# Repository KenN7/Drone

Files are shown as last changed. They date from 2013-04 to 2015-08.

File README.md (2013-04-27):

   ___          _                                     __ _   _               
  / __\___   __| | ___ _ __   __ _ _ __ ___   ___    /__\ |_| |__   ___ _ __ 
 / /  / _ \ / _` |/ _ \ '_ \ / _` | '_ ` _ \ / _ \  /_\ | __| '_ \ / _ \ '__|
/ /__| (_) | (_| |  __/ | | | (_| | | | | | |  __/ //__ | |_| | | |  __/ |   
\____/\___/ \__,_|\___|_| |_|\__,_|_| |_| |_|\___| \__/  \__|_| |_|\___|_|   
-----------------------------------------------------------------------------

Sources i use to build my quadrotor drone, you will find the source code and
the electronics based on dsPIC33 architecture.

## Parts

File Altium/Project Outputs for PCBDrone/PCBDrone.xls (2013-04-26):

Comment | Description | Designator | Footprint | LibRef | Quantity | Value
CAP | Capacitor | C7, C9, Cde, Cdecoup1, Cdecoup2, Cdecoup4 | C0805C | CAP | 6.0 | 10uF, 100nF, 100pF
CAP Pol | Polarized Capacitor | Creg1, Creg2 | RB.1/.3 | CAP Pol | 2.0 | 100uF, 220uF
LED2 | Typical RED, GREEN, YELLOW, AMBER GaAs LED | D1 | LED1206G | LED2 | 1.0
LED | Typical LED | Ddebug1 | LED1206R | LED | 1.0
LED | Typical LED | Ddebug2 | LED1206Y | LED | 1.0
LED | Typical LED | Ddebug3 | LED1206G | LED | 1.0
Diode 1N4001 | 1 Amp General Purpose Rectifier | DR1, DR2 | DO-41 | Diode 1N4001 | 2.0
200mA | Standard Fuse Holder | Fuse | Fuse Holder 5x20mm | Fuse | 1.0
Hole | Mounting Hole for screws | HOLE1, HOLE2 | SCREW | Hole | 2.0
Switch logique | Slide Switch with 2 positions | INT1 | Switch sur cosses 5.08mm | SW-SPDT | 1.0
Batterie | Header, 2-Pin | P1 | TERM2W-3.5 | Header 2 | 1.0
Header femelle | Header, 6-Pin | Paccelgyro | HDR1X6 | Header 6 | 1.0
alarme batterie faible | Header, 2-Pin | Palarm | HDR1X2 | Header 2 | 1.0
Header femelle | Header, 7-Pin | Pan | HDR1X7 | Header 7 | 1.0
jumper bind | Header, 2-Pin | Pbind | HDR1X2J | Header 2 | 1.0
Header 2 | Header, 2-Pin | Pext, Pext2 | TERM2W-3.5 | Header 2 | 2.0
PICkit | Header, 6-Pin, Right Angle | Pickit | HDR1X6H | Header ICSP | 1.0
Header bat | Header, 3-Pin | Prec1 | HDR1X3 | Header 3 | 1.0
Header thro | Header, 3-Pin | Prec2 | HDR1X3 | Header 3 | 1.0
Header aile | Header, 3-Pin | Prec3 | HDR1X3 | Header 3 | 1.0
Header elev | Header, 3-Pin | Prec4 | HDR1X3 | Header 3 | 1.0
Header rudd | Header, 3-Pin | Prec5 | HDR1X3 | Header 3 | 1.0
Header gear | Header, 3-Pin | Prec6 | HDR1X3 | Header 3 | 1.0
Header aux1 | Header, 3-Pin | Prec7 | HDR1X3 | Header 3 | 1.0
Header 3 | Header, 3-Pin | Psend1, Psend2, Psend3, Psend4, Pservo | HDR1X3 | Header 3 | 5.0
Header 2 | Header, 2-Pin | Puart | HDR1X2 | Header 2 | 1.0
RES | Resistor | R1, Rd1, Rd2, Rd3, Rp1, Rpup | C0805R | RES | 6.0 | 10k, 60
PTB78560x | Texas Instruments Regulators | Reg | PTB78560x | PTB78560x | 1.0
LM2937IMP-3.3 | 500 mA Low Dropout Regulator | Reg3 | TO-220-AB | LM2937IMP-3.3 | 1.0
SPST-NO | Tactile Switch 7.3mm, SMD | reset | SPST-NO | SPST-NO | 1.0
RES | Resistor | Rset2 | AXIAL-0.3 | RES | 1.0 | 14.3k
dsPIC33FJ64MC804-I/PT | High-Performance 16-bit Digital Signal Controller, 64 KB Flash, 16 KB RAM, 44-Pin TQFP, Industrial Temperature | U1 | TQFP-PT44_N | dsPIC33FJ64MC804-I/PT | 1.0

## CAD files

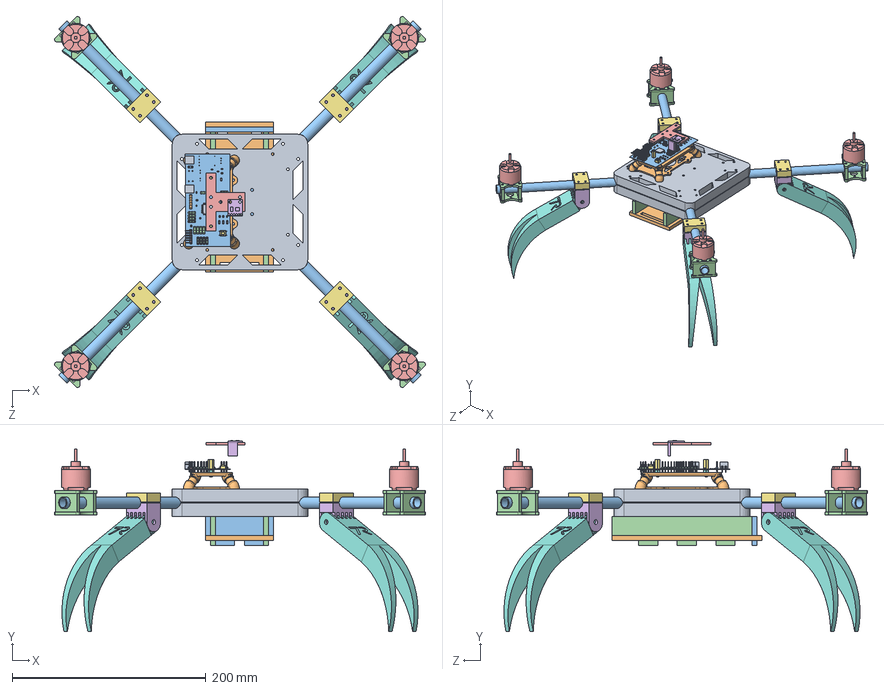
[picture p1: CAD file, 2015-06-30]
SolidWorks/Quadcopter V2.SLDASM
383.3 x 197.8 x 383.3 mm
Base V2
Anneau de fixation x 4
Tube carbone x 4
Support moteur x 4
moteur x 4
Fixation pied (bot) x 4
Fixation pied (top) x 4
Pied x 4
Base V2 (top)
Anti-vibration complet
Board
C0805C x 6
SW3dPS-LED1206G_Extruded x 2
SW3dPS-LED1206G_Extruded4 x 2
SW3dPS-LED1206G_Extruded2 x 4
SW3dPS-LED1206G_Extruded1 x 2
SW3dPS-LED1206G_Extruded3 x 2
SW3dPS-LED1206G_Board x 2
SW3dPS-LED1206R_Board
SW3dPS-LED1206R_Extruded3
SW3dPS-LED1206R_Extruded1
SW3dPS-LED1206R_Extruded x 2
SW3dPS-LED1206R_Extruded4
SW3dPS-LED1206R_Extruded2
SW3dPS-LED1206Y_Board
SW3dPS-LED1206Y_Extruded2 x 2
SW3dPS-LED1206Y_Extruded4
SW3dPS-LED1206Y_Extruded3
SW3dPS-LED1206Y_Extruded
SW3dPS-LED1206Y_Extruded1
User_Library-Spacer-M3-10mm x 2
User_Library-Female_screw_M3 x 2
User_Library-CTB93HD_2 x 2
pin_header_aw140-eg-g06d
pin_header_aw140-eg-g02d
pin_header_aw140-eg-g03d x 21
pin_header_aw140-ea-g06h
SW3dPS-0805_SMD_Resistor x 7
CircuitWorks-TACT_SMD_6X6
User_Library-TQFP-44_pins_TQFP_pin_TQFP_035_1 x 44
User_Library-TQFP-44_body_10x1_TQFP_10x10_1
Boite batterie (bot)
Boite batterie (fond)
Boite batterie (side) x 2
Support accelero
Accelero

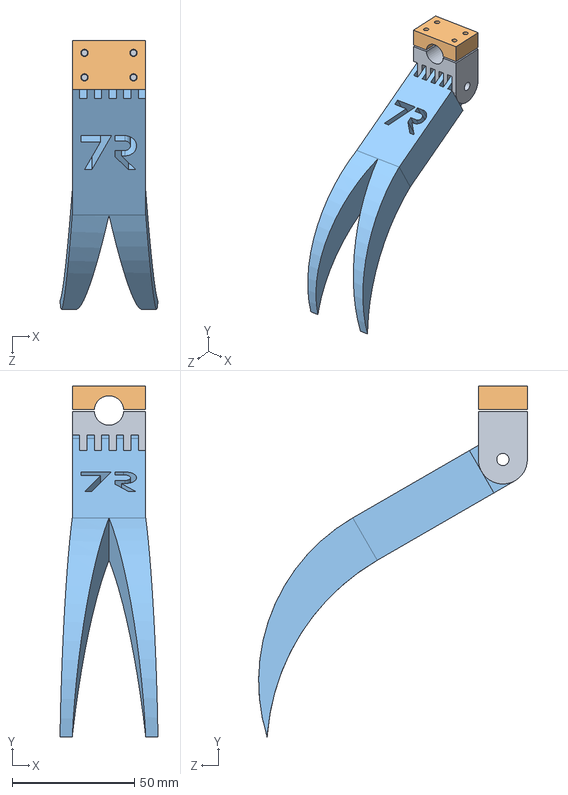
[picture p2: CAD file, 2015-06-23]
SolidWorks/Pied complet.SLDASM
40.0 x 143.3 x 109.7 mm
Fixation pied (bot)
Fixation pied (top)
Pied

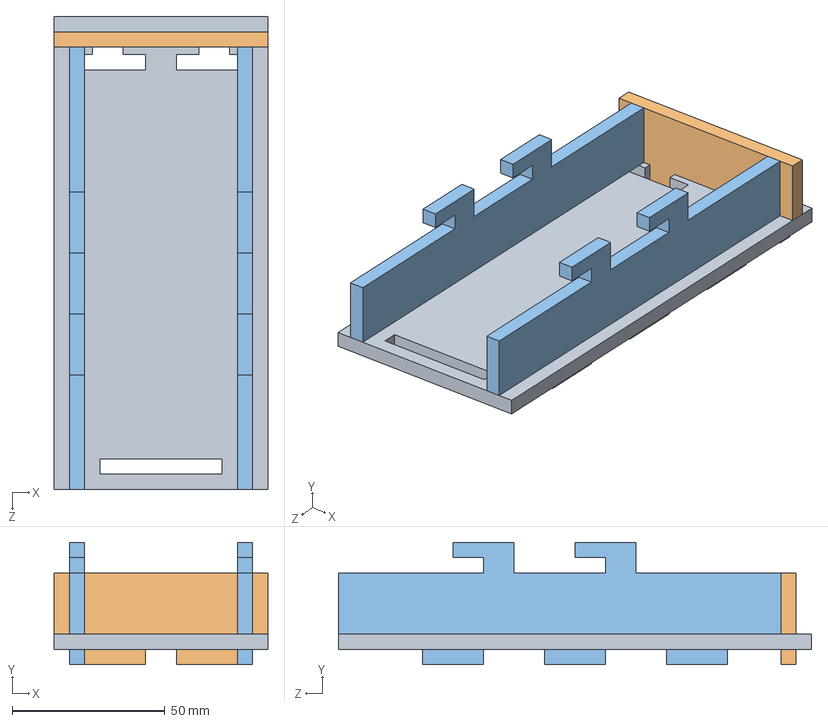
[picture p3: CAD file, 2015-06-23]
SolidWorks/Boite batterie.SLDASM
70.0 x 40.0 x 155.0 mm
Boite batterie (bot)
Boite batterie (fond)
Boite batterie (side) x 2

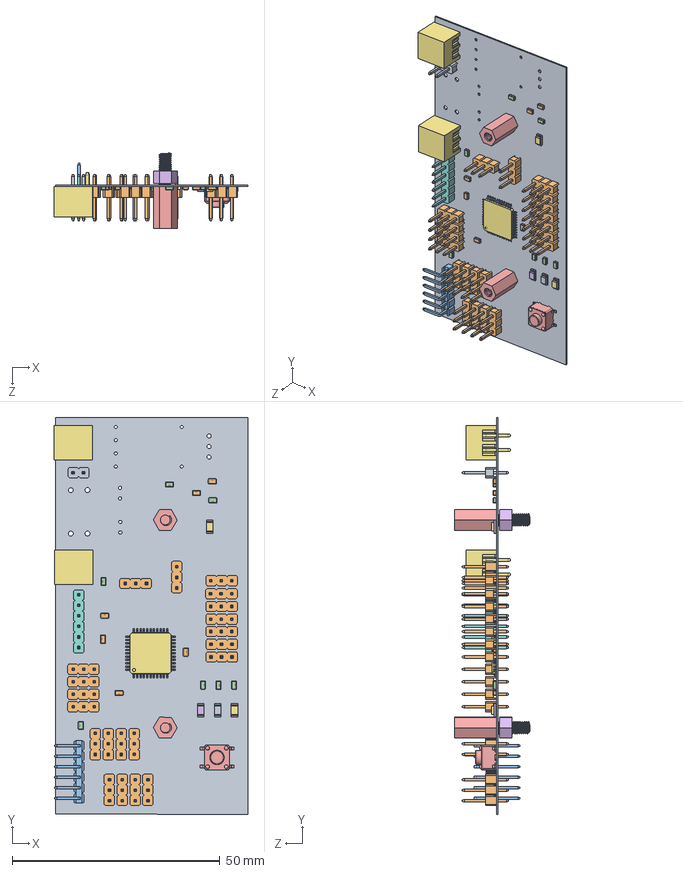
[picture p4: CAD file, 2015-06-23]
SolidWorks/PCBdroneV21.sldasm
46.7 x 95.6 x 18.2 mm
Board
C0805C x 6
SW3dPS-LED1206G_Extruded x 2
SW3dPS-LED1206G_Extruded4 x 2
SW3dPS-LED1206G_Extruded2 x 4
SW3dPS-LED1206G_Extruded1 x 2
SW3dPS-LED1206G_Extruded3 x 2
SW3dPS-LED1206G_Board x 2
SW3dPS-LED1206R_Board
SW3dPS-LED1206R_Extruded3
SW3dPS-LED1206R_Extruded1
SW3dPS-LED1206R_Extruded x 2
SW3dPS-LED1206R_Extruded4
SW3dPS-LED1206R_Extruded2
SW3dPS-LED1206Y_Board
SW3dPS-LED1206Y_Extruded2 x 2
SW3dPS-LED1206Y_Extruded4
SW3dPS-LED1206Y_Extruded3
SW3dPS-LED1206Y_Extruded
SW3dPS-LED1206Y_Extruded1
User_Library-Spacer-M3-10mm x 2
User_Library-Female_screw_M3 x 2
User_Library-CTB93HD_2 x 2
pin_header_aw140-eg-g06d
pin_header_aw140-eg-g02d
pin_header_aw140-eg-g03d x 21
pin_header_aw140-ea-g06h
SW3dPS-0805_SMD_Resistor x 7
CircuitWorks-TACT_SMD_6X6
User_Library-TQFP-44_pins_TQFP_pin_TQFP_035_1 x 44
User_Library-TQFP-44_body_10x1_TQFP_10x10_1

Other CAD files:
SolidWorks/Carte/Ddebug1.sldasm
SolidWorks/Carte/SW3dPS-LED1206R_352698192.sldasm
SolidWorks/Carte/SW3dPS-LED1206Y.sldasm
SolidWorks/Carte/SW3dPS-LED1206R_352697936.sldasm
SolidWorks/Carte/D1.sldasm
SolidWorks/Carte/reset.sldasm
SolidWorks/Carte/SW3dPS-LED1206G.sldasm
SolidWorks/Carte/SW3dPS-LED1206G_352698192.sldasm
SolidWorks/Carte/SW3dPS-LED1206G_352697808.sldasm
SolidWorks/Carte/SW3dPS-LED1206R_352697808.sldasm
SolidWorks/Carte/SW3dPS-LED1206Y_352697680.sldasm
SolidWorks/Carte/Paccelgyro.sldasm
SolidWorks/Carte/Palarm.sldasm
SolidWorks/Carte/C7.sldasm
SolidWorks/Accelero.SLDPRT
SolidWorks/Anneau de fixation.SLDPRT
SolidWorks/Anti-vibration (bot).SLDPRT
SolidWorks/Anti-vibration (top).SLDPRT
SolidWorks/Anti-vibration complet.SLDPRT
SolidWorks/Base (top).SLDPRT
SolidWorks/Base V2 (top).SLDPRT
SolidWorks/Base V2.SLDPRT
SolidWorks/Boite batterie (bot).SLDPRT
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

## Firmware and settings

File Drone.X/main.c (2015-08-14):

/*
* Template dsPIC33F
* Compiler : Microchip xC16
* �C : 33FJ64MC802
* Juillet 2012
*    ____________      _           _
*   |___  /| ___ \    | |         | |
*      / / | |_/ /___ | |__   ___ | |_
*     / /  |    // _ \| '_ \ / _ \| __|
*    / /   | |\ \ (_) | |_) | (_) | |_
*   /_/    |_| \_\___/|____/ \___/'\__|
*			      7robot.fr
*/

#include <p33Fxxxx.h>      /* Includes device header file                     */
#include <stdint.h>        /* Includes uint16_t definition                    */
#include <stdbool.h>       /* Includes true/false definition                  */
#include "header.h"        /* Function / Parameters                           */
#include <libpic30.h>
#include <timer.h>

/******************************************************************************/
/* Global Variable Declaration                                                */
/******************************************************************************/
/* i.e. uint16_t <variable_name>; */
volatile float throttle_input;
volatile float roll_input;
volatile float pitch_input;
volatile float yaw_input;

/******************************************************************************/
/* Configuartion                                                              */
/******************************************************************************/

// Select Oscillator and switching.
_FOSCSEL(FNOSC_FRCPLL & IESO_OFF);
// Select clock.
_FOSC(POSCMD_NONE & OSCIOFNC_ON & IOL1WAY_OFF & FCKSM_CSDCMD);
// Watchdog Timer.
_FWDT(FWDTEN_OFF);
// Select debug channel.
_FICD(ICS_PGD1 & JTAGEN_OFF);


/******************************************************************************/
/* Main Program                                                               */
/******************************************************************************/

int16_t main(void)
{   
    // Initialize IO ports and peripherals.
    ConfigureOscillator();
    InitApp();

//    eteindre();
//    __delay_ms(500);
//    arc_en_ciel(10);

    while(1){
//      stack_point(30);
//      __delay_ms(500);
      
    }


}
////////////////////////////////////////////////////////////////////////////////

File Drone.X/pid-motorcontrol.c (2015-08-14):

/* 
 * File:   pid-motorcontrol.c
 * Author: Ken
 *
 * Created on 28 avril 2013, 17:34
 */

#include <stdio.h>
#include <stdlib.h>
#include <p33Fxxxx.h>      /* Includes device header file                     */
#include <stdint.h>        /* Includes uint16_t definition                    */
#include <stdbool.h>       /* Includes true/false definition                  */
#include "header.h"        /* Function / Parameters                           */
#include <libpic30.h>

/******************************************************************************/
/*                            Definitions                                     */
/******************************************************************************/
#define MIN_PWM 5500
#define MAX_PWM 9000 // TODO tweakage necessaire !! les controlleurs se mettent en BO pour des raisons inconnues
#define MES_MIN 6000
#define MES_MAX 9000
//#define MES_MID (MES_MIN+((MES_MAX-MES_MIN)/2))
#define MES_MID 7500
#define PLAGE_MOTOR (MAX_PWM-MIN_PWM)
#define PLAGE_XANGLE 20
#define PLAGE_YANGLE 20
#define PLAGE_ZRATE 50

/******************************************************************************/
/*                         Global variables                                   */
/******************************************************************************/
extern volatile float throttle_input;
extern volatile float roll_input;
extern volatile float pitch_input;
extern volatile float yaw_input;

extern volatile float filtered_angles[2];
extern volatile float filtered_angles2[2];
extern volatile float dataA[2];
extern volatile float dataG[3];
/*
 * c'est la fête du global dans le PID !!
 */
volatile float PID_XOUTPUT;
volatile float PID_YOUTPUT;
volatile float PID_ZOUTPUT;
volatile float PREVIOUS_ERROR[3]; //X, Y , Z
volatile float ERROR[3]; //X, Y , Z
volatile float DIFFERENTIAL[3];
volatile float INTEGRAL[2];

//float KP = 4.0; //25 27/6/12
//float KI = 0.3; //85 5/6/12
//float KD = 0.8; //7 27/6/12
//float ZKP = 5.0; //40 8/6/12
//float ZKD = 0.0; //25 8/6/12

//TODO teweaker les coefs
static float XKP = 10; //25 27/6/12 //0.2  // BAISSEERRRR   //20
static float XKI = 0; //85 5/6/12  //TESERRR               //10
static float XKD = 0; //7 27/6/12 // TESTERRRR              //5

static float YKP = 10;     //Ku=5 ==> Kp=0.6*Ku=3         //10 ==> 6
static float YKI = 0;     //Tu=1sec ==> Ki=2Kp/Tu=6       //1  ==> 12
static float YKD = 0;     //Kd=Kp*Tu/8=0.375              //0.75

static float ZKP = 20; //40 8/6/12
static float ZKD = 0; //25 8/6/12

static int Kdir = 1;


static volatile float TZrate = 0;
static volatile float TXangle = 0;
static volatile float TYangle = 0;

void PID()
{
    TZrate = PLAGE_ZRATE*(float)((float)yaw_input - MES_MID)/(MES_MAX - MES_MIN);
    if(TZrate < 1 && TZrate > -1) {TZrate = 0;}
    TZrate *= Kdir;

    TXangle = PLAGE_XANGLE*(float)((float)roll_input - MES_MID)/(MES_MAX - MES_MIN);
    if(TXangle < 1 && TXangle > -1) {TXangle = 0;}
    TXangle *= Kdir;

    TYangle = PLAGE_YANGLE*(float)((float)(pitch_input - MES_MID)/(MES_MAX - MES_MIN));
    if(TYangle < 1 && TYangle > -1) {TYangle = 0;}
    TYangle *= Kdir;
    
                               //Pour l'asserv, on convertit les valeurs de
                                //5000 à 10000 de l'entree en angle avec une regle de 3
                                // c'est ANGLE_RANGE qui fixe l'angle max.
                                // l'angle max choisi est 30deg, donc de -15 a +15
                                // je pense quon peut aller bien au dessus.
                                // il est peut etre habile de deporter les calculs
                                // dans le mm fichier que le PID pour limiter les
                                // variables globales gitanes entres fichiers.


   PREVIOUS_ERROR[0] = ERROR[0];
   PREVIOUS_ERROR[1] = ERROR[1];
   PREVIOUS_ERROR[2] = ERROR[2];

// avant bullshit MP6050
    ERROR[0] = TXangle - filtered_angles[0]; //roll
    ERROR[1] = TYangle - filtered_angles[1]; //pitch
    ERROR[2] = TZrate - dataG[2]; //speed asserv for yaw
// TODO refactorer et remettre ci dessus et enlever bullshit ci dessous
    //ERROR[0] = TXangle - COMPLEMENTARY_XANGLE; //roll
    //ERROR[1] = TYangle - COMPLEMENTARY_YANGLE; //pitch
    //ERROR[2] = TZrate - GYRO_ZRATE; //speed asserv for yaw

    //DIFFERENTIAL[0] = (ERROR[0] - PREVIOUS_ERROR[0])/dt;
    //DIFFERENTIAL[1] = (ERROR[1] - PREVIOUS_ERROR[1])/dt;

    // de même ici
    DIFFERENTIAL[0] = -dataG[0];
    DIFFERENTIAL[1] = -dataG[1];
    DIFFERENTIAL[2] = -(ERROR[2] - PREVIOUS_ERROR[2])/dt;
    //TODO de même virer code ci dessous et remettre ci dessus
    //DIFFERENTIAL[0] = -GYRO_XRATE;
    //DIFFERENTIAL[1] = -GYRO_YRATE;
    //DIFFERENTIAL[2] = -GYRO_ZRATE;

    INTEGRAL[0] += ERROR[0]*dt;
    INTEGRAL[1] += ERROR[1]*dt;

    if(INTEGRAL[0]> 0.5) {INTEGRAL[0] = 0.5;}
    else if(INTEGRAL[0] < -0.5) {INTEGRAL[0] = -0.5;}
    if(INTEGRAL[1] > 0.5) {INTEGRAL[1] = 0.5;}
    else if(INTEGRAL[1] < -0.5) {INTEGRAL[1] = -0.5;}

    PID_XOUTPUT = ERROR[0]*XKP + DIFFERENTIAL[0]*XKD + INTEGRAL[0]*XKI;
    PID_YOUTPUT = ERROR[1]*YKP + DIFFERENTIAL[1]*YKD + INTEGRAL[1]*YKI;
    PID_ZOUTPUT = ERROR[2]*ZKP + DIFFERENTIAL[2]*ZKD;

    if(PID_ZOUTPUT > 1000){PID_ZOUTPUT = 1000;}
    else if (PID_ZOUTPUT < -1000){PID_ZOUTPUT = -1000;}
}

static volatile float throttle;
static volatile int OC1_output;
static volatile int OC2_output;
static volatile int OC3_output; //x roll, y pitch
static volatile int OC4_output;

void Update_PWM()
{   
    if(throttle_input <= 5700)
    {
        throttle = 0;
    }
    else
    {
        throttle = (float)(throttle_input - MES_MIN)/(MES_MAX-MES_MIN);
    }
    if (throttle > 1.0) throttle=1.0;
    if(throttle < 0.0) throttle=0.0;

    if(throttle==0.0)
    {
	OC1RS = 5000;
	OC2RS = 5000;
	OC3RS = 5000;
	OC4RS = 5000;
    }
    else //X config
    {
        OC1_output = -0.7071*PID_XOUTPUT + -0.7071*PID_YOUTPUT + PID_ZOUTPUT + MIN_PWM + PLAGE_MOTOR*throttle; // right front (Psend1)
	OC2_output = -0.7071*PID_XOUTPUT + 0.7071*PID_YOUTPUT - PID_ZOUTPUT + MIN_PWM + PLAGE_MOTOR*throttle;  //right back (Psend2)
        
	OC3_output = 0.7071*PID_XOUTPUT + 0.7071*PID_YOUTPUT + PID_ZOUTPUT + MIN_PWM + PLAGE_MOTOR*throttle; //left back (Psend3)
	OC4_output = 0.7071*PID_XOUTPUT + -0.7071*PID_YOUTPUT - PID_ZOUTPUT + MIN_PWM + PLAGE_MOTOR*throttle; //left front (Psend4)

	if(OC1_output > MAX_PWM) {OC1_output = MAX_PWM;}
	if(OC2_output > MAX_PWM) {OC2_output = MAX_PWM;}
	if(OC3_output > MAX_PWM) {OC3_output = MAX_PWM;}
	if(OC4_output > MAX_PWM) {OC4_output = MAX_PWM;}

	if(OC1_output < MIN_PWM) {OC1_output = MIN_PWM;}
	if(OC2_output < MIN_PWM) {OC2_output = MIN_PWM;}
	if(OC3_output < MIN_PWM) {OC3_output = MIN_PWM;}
	if(OC4_output < MIN_PWM) {OC4_output = MIN_PWM;}

	//OC1RS = OC1_output;
	OC2RS = OC2_output;
	//OC3RS = OC3_output;
	OC4RS = OC4_output;

    }
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

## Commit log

2013-04-26 debut et fin du routage de la carte
    [DroneRegul.SchDoc, DroneSch.SchDoc, PCBDrone.PrjPCB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]
2013-04-26 gerber et logo
    [DroneRegul.SchDoc, PCBDrone.PrjPCB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]
2013-04-28 codage de l'i2c
    merci la lib de microship!
2013-04-28 process des donnees i2c
    still untested
2013-04-28 debut process pid et init
    sill untested
2013-05-02 pic avec 100nF et 10uF c'est mieux
    [DroneSch.SchDoc]
2013-05-17 amelioration
    code tester accel gyro work
2013-05-17 correction du code PWM
    devrait marcher
    [T1-init-filter.c, outputcompare.c, pid-motorcontrol.c]
2013-05-18 ajout fonction calib, debut uart, filtrage
2013-05-18 code machine get UART
    reste a faire l'envoi sur uart
2013-05-18 amelio du type de message uart
    sidordre 1024 1024
2013-05-19 debut asserv, deport des calculs dans PID
2013-05-21 code a tester, pid fini
2013-05-23 ajout debug uart
2013-05-27 nouvelle version PCB et reduction bruit accel
    [DroneRegul.SchDoc, DroneSch.SchDoc, PCBdrone.PcbDoc]
2014-05-01 petites modif du code, il faut faire une nouvelle carte..
2014-05-01 nouvelle version pcb
    [DroneRegul.SchDoc, DroneSch.SchDoc, PCBDrone.PrjPCB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]
2014-05-03 pcb routé
    [DroneRegul.SchDoc, DroneSch.SchDoc, PCBDrone.PrjPCB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]
2014-08-30 correction HeisenBug et ajout support capteur
    [T1-init-filter.c, accelgyro.c, i2c_func.c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]
2015-06-16 Ajout fichier SolidWorks
    [Anneau de fixation.SLDPRT, Base (top).SLDPRT, Fixation base.SLDPRT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]
2015-06-17 Pied et batterie SW
    [Anneau de fixation.SLDPRT, Base (top).SLDPRT, Board.sldprt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]
2015-06-18 Avance du SW
    [Anti-vibration (bot).SLDPRT, Anti-vibration (top).SLDPRT, Anti-vibration complet.SLDPRT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]
2015-06-19 Drone V2 SW
    [Board.sldprt, C0805C.sldprt, C7.sldasm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]
2015-06-23 Maj SW
    [Accelero.SLDPRT, Anti-vibration complet.SLDPRT, Base V2 (top).SLDPRT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]
2015-06-30 Library Led Circle
    [Fixation anti-vibra carte.SLDPRT, Fixation anti-vibra carte.STL, Quadcopter V2.SLDASM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]
2015-07-23 mp6050 fonctionnel, correction bug yaw, ajout securité sur input
    [T1-init-filter.c, i2c_func.c, main.c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]
2015-07-24 Complementary filter OK
2015-08-14 Version fin de stage Denis
